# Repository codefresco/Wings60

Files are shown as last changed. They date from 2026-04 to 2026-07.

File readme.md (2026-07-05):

# Wings60

Wings60 is an open source split keyboard designed after trying many existing split layouts.

## Why this layout

This keyboard is different in:

- Improved key access for the thumb cluster, two 1.5u key with good access.
- Uses a natural thumb cluster orientation selected after testing many existing layouts.
- Uses the most popular column stagger.
- Keeps the same PCB usable for wired or wireless builds, including a power slide switch, JST PH2.0 battery plug, and between-halves interconnects on the PCB.
- Uses USB-C for wired interconnect between halves, it can be hot-plugged without damaging microcontrollers.
- Supports pro-micro pinout controllers such as Nice!Nano, Pro Micro ATmega32u4, and Pro Micro RP2040.
- Uses low-power RGB LEDs (SK6803 mini-e), which draw less power than common WS2812B and SK6812 variants.
- Includes a slide switch to cut LED power for zero LED idle current in power-conscious assemblies.
- Stays compact while keeping a top number row.

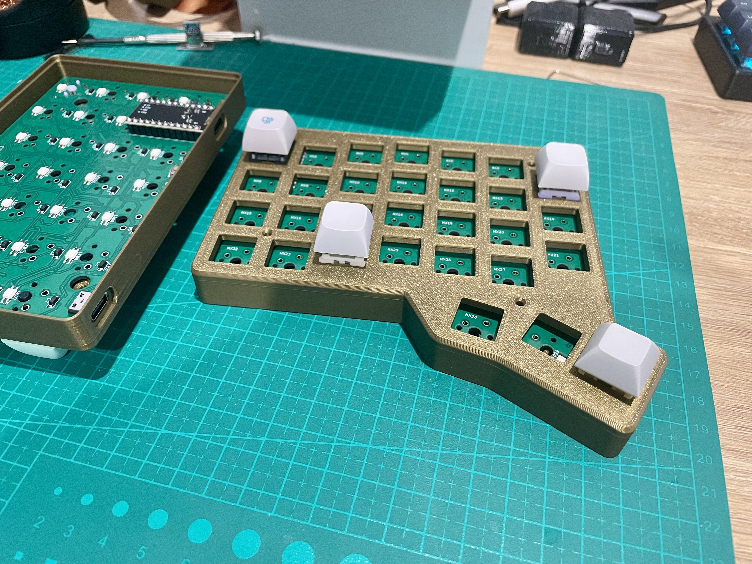
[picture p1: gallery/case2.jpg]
Wings60 case view


## How to assemble

> [!WARNING]
> If you use a 3V microcontroller (for example Nice!Nano or RP2040), do not plug a powered USB cable into the between-halves interconnect USB-C port. With a standard usb c cable and device, this would not be an issue bacause the CC pin on the interconnect is not connected. With a floating CC pin the device would not power the USB-C port. However, some USB-A to USB-C cables or devices do not comply with this standard and present 5v to the USB-C VBUS anyway, and this can damage the microcontroller. To make it mistake proof:
> - For nice! nano compatible and wireless builds print the case with interconect port covered
> - For wired builds with 3V microcontrollers do not connect he VCC pin on microcontroller to the pcb (don't pin if using mill max or similar pins, clip the pin if using ez solder, etc.) and bridge the VCC pin of the PCB to RAW using a short wire on back of the PCB

> [!WARNING]
> Before soldering switches, make sure the microcontroller USB connector is clearly accessible in your chosen case. After switches are soldered, the case top is sandwiched between switches and PCB, and changing the top case becomes difficult. If you want to be able to remove the PCB more easily, check the PCB-mount-switches case variant in [case](./case).

### Bill of materials

- See designs in [case](./case), pick one and print it. You can also design your own case around the [Case design outline](./case/design-outline), both dxf and svg are included.
- Sockets for MCU: one of EZ-Solder Machine Sockets or a 40-pin machined IC breakable female header strip with Mill-Max pins is recommended for a total socket height of 4.5-5mm. This works best with the 3D printable case designs in [case](./case). Check USB connector height after assembly against the case USB opening. If your USB sits higher/lower, use the adjustable USB case variant described in [case/readme.md](./case/readme.md). A good guide to socketing microcontrollers is available here: [Machine pin socket guide](https://github.com/joric/nrfmicro/wiki/Sockets#machine-pin-socket)
- Two pro micros: use any board with firmware already available in [firmware](./firmware), or any pro-micro-pinout compatible board and adjust firmware as needed. For wireless, use Nice!Nano or compatible SuperMini nRF52840.
- Either 4x 9-10mm standoffs with 4x M2x8 and 4x M2x4 screws for each half, or 4x M2x4 heat inserts with the heat-insert-compatible case bottom. See [case/readme.md](./case/readme.md).
- Non-slip rubber feet, 4x per half. 6mm diameter x 2mm height works well.
- [Wired only] A USB-C to USB-C cable for connecting the right and left halves.
- [Wireless only] A JST PH2.0 battery up to 5mm height. Check dimensions against the case if using the designs in [case](./case).
- Switches and keycaps.

### Wired build

1. Flash firmware using instructions here [firmware/readme.md](./firmware/readme.md)
2. Solder and socket the microcontrollers to PCBs, **face down**. USB side must face the PCB. A good socketing guide: [Splitkb microcontroller guide](https://docs.splitkb.com/product-guides/aurora-series/build-guide/microcontrollers)
3. Check USB height to make sure it fits the case designs in [case](./case). If it fits fixed-USB, use that variant; otherwise adjust USB height in the movable/adjustable variant in your slicer.
4. Fit switches to the case, minding pin orientation.

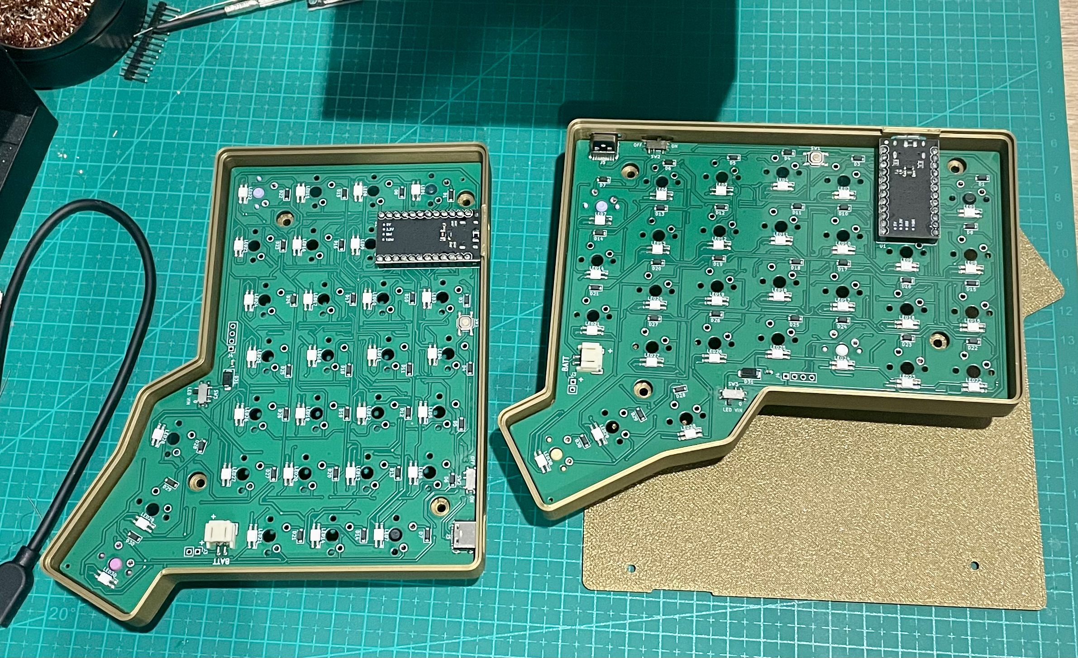
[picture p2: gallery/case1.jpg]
Assembly orientation


5. Fit the PCB to the case with flat side toward switches and components facing away from switches, so switch pins come out through the PCB. PCB should rest on the bottom of the switches. You may need gentle pressure for switch mounting pins to pop in.
6. Check no switch has popped out, and all switches are firmly seated on top of the case top side. Then solder all switch legs to the PCB.
7. If using standoff bottoms, screw each standoff to the case with M2x8 screws. V-shaped heads sit flush in the top-side recesses.
8. Screw case bottoms to standoffs using M2x4 screws, then apply non-slip feet.
9. If using heat-insert bottoms, install heat inserts and fit the bottom to the top using M4x8 screws.

The halves can now be connected using the USB-C cable. Connect one microcontroller to your PC (either half, but not both).

Use [Vial](https://get.vial.today/) to configure the keyboard. Configuration is saved to the half connected to the PC.

### Wireless build

TBD

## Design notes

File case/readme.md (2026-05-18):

## Warning
Before soldering switches, confirm that the case USB opening lines up with your microcontroller's USB port position on the PCB.

| Example 1 | Example 2 |
| --- | --- |
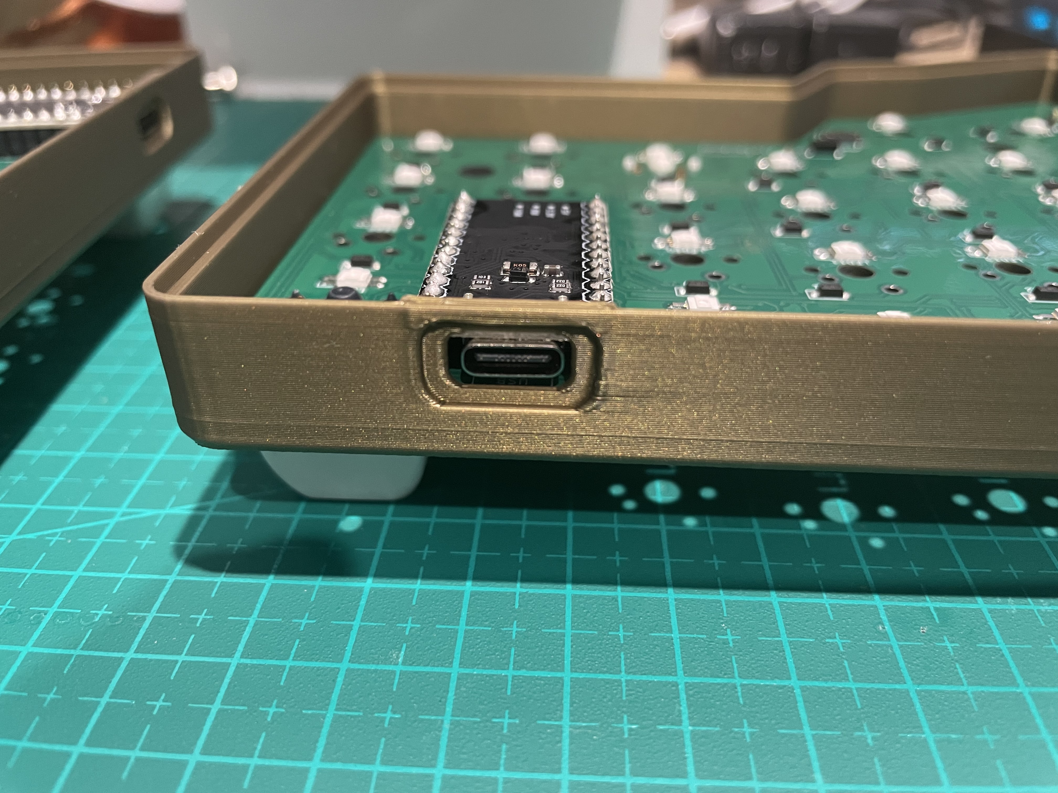
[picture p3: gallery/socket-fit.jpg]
Socket fit
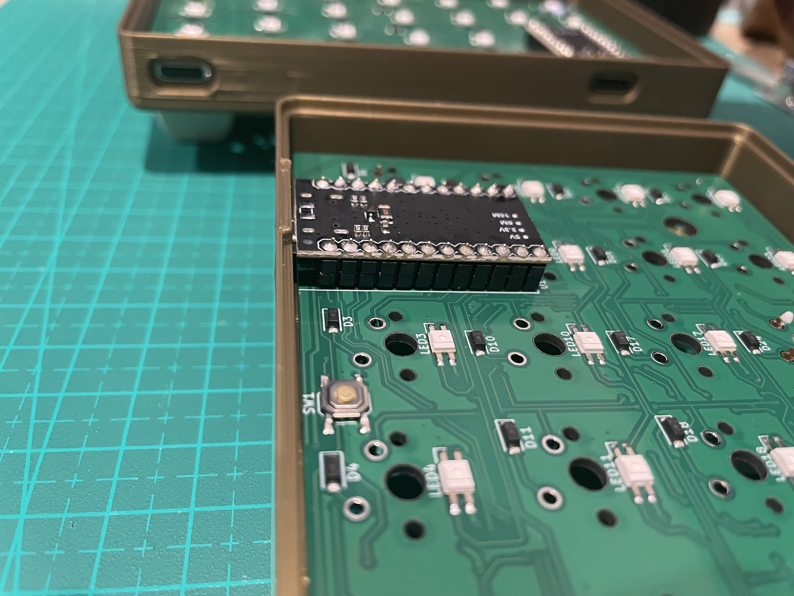
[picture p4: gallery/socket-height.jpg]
Socket height
|  |  |

## Printable Case Types
- **Fixed-height USB opening** (`*-usb-fixed-5mm.3mf`)
	- For total microcontroller socket height of **4.5-5 mm**.
	- Intended for controllers with the USB port mounted on top of the PCB.
- **Movable USB opening** (`*-usb-movable.3mf`)
	- Includes a USB opening as a **negative part** (for Bambu Studio).
	- You can move this part up or down on the **Z axis** to match your board and socket height.

## Which Case Should You Use?
- **`case-wired-usb-fixed-5mm.3mf`**
	- For wired builds with total socket height of **4.5-5 mm**.
	- For MCU boards with the USB connector on top of the PCB.
	- The power-switch opening is covered.

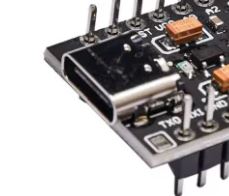
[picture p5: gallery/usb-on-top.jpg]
MCU with USB on top
	
- **`case-nice-nano-and-rp2040-usb-movable.3mf`**
  - For wired or wireless builds with total socket height of **4.5-5 mm**.
  - For boards with a USB connector recessed into the board (for example, nice!nano or Tenstar RP2040 Pro Micro).
  - Includes a power-switch opening by default.
  - You can move the USB negative object in Z and optionally remove the power-switch opening for wired builds.
  - This is the most adjustable 3MF option.

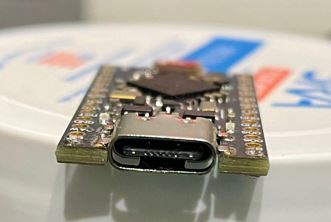
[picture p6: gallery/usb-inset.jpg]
MCU with USB inset
  
- **`case-wired-usb-movable.3mf`**
	- For wired builds.
	- Includes a movable negative object for the USB opening.
	- Adjust USB opening height to fit your specific MCU and mounting height.
- **`case-for-pcb-mount-switches.3mf`**
	- Designed for PCB-mount switches and is less forgiving than other options.
	- The top plate is optional and removable; it does not hold switches permanently.
	- Switches sit directly on the PCB in this build.
	- If you use the top plate, install it before soldering and ensure:
		- switches are fully seated on the PCB,
		- the plate is fully touching the PCB.
	- Due to tight tolerances, soldering switches first may prevent the top case from fitting later.
	- Recommended approach: tape the plate to the PCB, solder switches in the corners first, then solder the rest.

## Bottom, Hardware, and Fasteners
- The bottom included in each 3MF is designed for **9-10 mm standoffs**.
- Use **M2x8 screws (4 pcs)** for the top.
- Use **M2x4 screws (4 pcs)** for the bottom.
- Use **4 standoffs per side**.

## Heat-Insert Bottom Variant
A separate bottom file is available: **`bottom-for-heat-inserts.3mf`**.
- Accepts **M2x4 heat inserts** instead of standoffs.
- Use inserts intended for plastic insertion (not inserts for injection-molded plastic).
- Install inserts accurately for proper fit.
- This variant can provide a better sound profile.

Wings60 Case Bottom

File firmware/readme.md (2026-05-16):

# Wings60 Firmware

This directory contains both source and precompiled firmware for the Wings60 keyboard.

- Source code is in [wings60](wings60) if you want to modify or compile firmware yourself. See [wings60/readme.md](wings60/readme.md) for details.
- Compiled firmware is available in [release](release), ready to flash onto your keyboard.

## Flashing Firmware

| Microcontroller Type | Flashing Guide |
| --- | --- |
| Promicro Atmega32u4 | [Guide](./release/promicro_atmega32u4/readme.md) |
| Nice! Nano (or compatible) | TBD |
| Promicro RP2040 | [Guide](./release/promicro_rp2040/readme.md) |
| STM32 Blackpill | TBD |

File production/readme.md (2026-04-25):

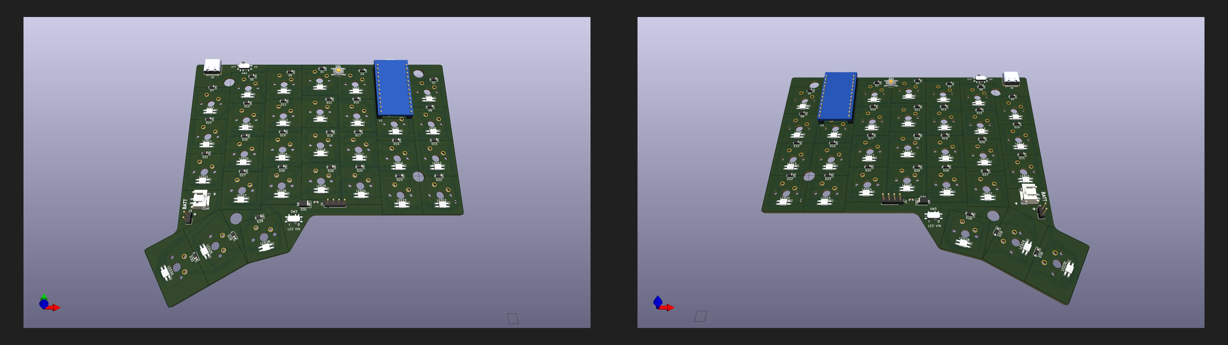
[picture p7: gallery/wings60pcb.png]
Wings60 PCB


## Production Files

You can order this split keyboard from any major PCB manufacturer using the production-ready files in this directory.

- `left/` contains manufacturing files for the left PCB
- `right/` contains manufacturing files for the right PCB

## Example: Ordering from JLCPCB

1. Open JLCPCB and start a new PCB order.
2. Upload the left and right Gerber ZIPs separately (one order per side).
3. Confirm board specs (dimensions, thickness, copper weight, solder mask color, and finish).
4. Keep defaults unless you need specific changes.
5. Add both boards to cart, review, and place the order.

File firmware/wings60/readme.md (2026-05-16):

# Wings60

wings60

* Keyboard Maintainer: [hamid](https://github.com/codefresco)
* Hardware Supported: *Atmega32u4, Weact Blackpill F411, R2040*

See the [build environment setup](https://docs.qmk.fm/#/getting_started_build_tools) and the [make instructions](https://docs.qmk.fm/#/getting_started_make_guide) for more information. Brand new to QMK? Start with our [Complete Newbs Guide](https://docs.qmk.fm/#/newbs).

## Building firmware for Wings60

### Pro micro atmega32u4
Variants with an avr pro micro have less firmware space available, so some vial features are disabled and only the 3 layer keymap fits. Please review in rules.mk.

Compile firmware (or grab from release directory) for left and right sides, for atmega32u4.
```
qmk compile -kb wings60/avr/left -km vial3layer
qmk compile -kb wings60/avr/right -km vial3layer
```

To flash the resulting `wings60_avr_left_vial3layer.hex` and `wings60_avr_right_vial3layer.hex` file use avrdude:

```
avrdude -p atmega32u4 -c avr109 -P [YOUR_COM_PORT] -U flash:w:wings60_avr_left_vial3layer.hex:i
```
replace [YOUR_COM_PORT] with the com port that the pro micro is connected and double tap SW1 on the pcb (reset button) before flashing. Repeat for the right side.

## Pro micro RP2040Based on a raspberry pico rp2040 with pro micro footprint.

Compile and flash firmware (or grab from release directory) for left and right sides, for rp2040.
```
make wings60/rp2040:vial:uf2-split-left
make wings60/rp2040:vial:uf2-split-right
```
Each command also generates a `wings60_rp2040_vial.uf2` in `vial-qmk` root directory. If you want to keep that file, rename after each half and copy it to somewhere else so it does not get overwrittern by the next half.

**Note:** some borads do not go into bootloader by double tapping reset, for first flash you might have to hold the boot switch and connect the usb. Subsequent flashes will work by double tapping the reset key on the PCB.

## Bootloader

Enter the bootloader in 3 ways:

* **Bootmagic reset**: Hold down the key at (0,0) in the matrix (usually the top left key or Escape) and plug in the keyboard
* **Physical reset button**: Double tap the SW1 butoon on the PCB
* **Keycode in layout**: Press the key mapped to `QK_BOOT` if it is available

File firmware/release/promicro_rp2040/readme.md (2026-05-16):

# Flashing Pro Micro (RP2040) Firmware

This directory contains prebuilt firmware for for the **Pro Micro RP2040** version of the Wings60:

- `wings60_rp2040_left_vial.uf2`
- `wings60_rp2040_right_vial.uf2`

Flash the **left** file to the left half, and the **right** file to the right half.

## Before you start

You will need to put your RP2040 board into bootloader mode. This brings up a drive where you can copy the uf2 file there.

If you have brand new boards they should go into bootloader and bring up the drive after connecting them to your PC via USB. However, some boards already have firmware on and depending on what firmware is on the board you should be able to either **double tap reset (or short reset pin to ground twice)** to enter bootloader, **or hold the boot switch and connect USB.** So it would be a good idea to **flash firmware to your boards before socketing them into Wings60 PCB.**

After you flash Wings60 firmware once, subsequent flashing can be done by double tapping the reset switch **SW1** on the Wings60 pcb.

## Important notes

- Flash **one half at a time**
- Unplug the other half while flashing to avoid confusion

## Troubleshooting

### Double tapping reset switch does not put the contrller into bootloader

This is common with some boards, to flash you would have to hold the boot switch on the board if it has one, or short the Boot pin to ground and connect the board to USB.

### Columns on the keyboard are reversed

This happens if you flash the right side firmware to left and vice versa. Flash the correct half to fix.

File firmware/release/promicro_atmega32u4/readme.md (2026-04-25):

# Flashing Pro Micro (ATmega32U4) Firmware

This folder contains prebuilt firmware for the **Pro Micro ATmega32U4** version of Wings60:

- `wings60_avr_left_vial3layer.hex`
- `wings60_avr_right_vial3layer.hex`

Flash the **left** file to the left half, and the **right** file to the right half.

## Before you start

You will need:

- A USB cable that supports data
- `avrdude` installed on your computer
- The correct COM port for the Pro Micro you are flashing
- A way to reset the controller into bootloader mode

If you need to reset the MCU, you can use the **SW1 reset switch on the PCB**.

## Important notes

- Flash **one half at a time**
- Unplug the other half while flashing to avoid confusion
- The keyboard may show up on a different COM port after reset; this is normal on many Pro Micro boards
- The bootloader stays available only for a short time, so have the command ready before resetting

## Install avrdude

If `avrdude` is not already installed, install it first.

Common options on Windows:

- Use QMK MSYS if you already use QMK tools
- Install `avrdude` through a package manager such as Scoop or Chocolatey
- Use an existing AVR toolchain installation if you already have one

After installation, open a terminal and confirm it works:

```powershell
avrdude -?
```

If that prints help text, `avrdude` is available.

## Find the COM port

1. Plug in the half you want to flash.
2. Open **Device Manager**.
3. Expand **Ports (COM & LPT)**.
4. Note the COM port for the Pro Micro, for example `COM7`.

If you do not see it, try another USB cable or USB port.

## Flash the left half

Open a terminal in this folder and run:

```powershell
avrdude -p atmega32u4 -c avr109 -P COM7 -U flash:w:wings60_avr_left_vial3layer.hex:i
```

Replace `COM7` with your actual port.

If `avrdude` cannot connect, reset the MCU and try again:

1. Press the **SW1 reset switch on the PCB**.
2. If needed, press it twice quickly to enter the bootloader.
3. Run the flash command again immediately.

When flashing succeeds, `avrdude` will report that writing and verification completed.

## Flash the right half

Open a terminal in this folder and run:

```powershell
avrdude -p atmega32u4 -c avr109 -P COM7 -U flash:w:wings60_avr_right_vial3layer.hex:i
```

Again, replace `COM7` with the correct port for the right half.

If needed, use the **SW1 reset switch on the PCB** before running the command.

## Recommended flashing order

1. Unplug both halves.
2. Plug in the left half.
3. Flash `wings60_avr_left_vial3layer.hex`.
4. Unplug the left half.
5. Plug in the right half.
6. Flash `wings60_avr_right_vial3layer.hex`.

## Troubleshooting

### `ser_open(): can't open device`

Usually means the COM port is wrong or the board is not in bootloader mode.

Try this:

- Check the COM port again in Device Manager
- Press the **SW1 reset switch on the PCB** and retry quickly
- Unplug and reconnect the board
- Try a different USB cable

### The COM port changes after reset

This is common for Pro Micro boards. Watch Device Manager while pressing **SW1** and use the port that appears in bootloader mode.

### Flash starts but fails part way through

Try this:

- Disconnect the other half
- Plug directly into the PC instead of a hub
- Reset with **SW1** and retry
- Make sure no other program is using the same COM port

## Summary

- Left half: `wings60_avr_left_vial3layer.hex`
- Right half: `wings60_avr_right_vial3layer.hex`
- MCU: `atmega32u4`
- Programmer: `avr109`
- Reset method: **SW1 reset switch on the PCB**

Use the same `avrdude` command for both halves and only change:

- The COM port
- The `.hex` filename

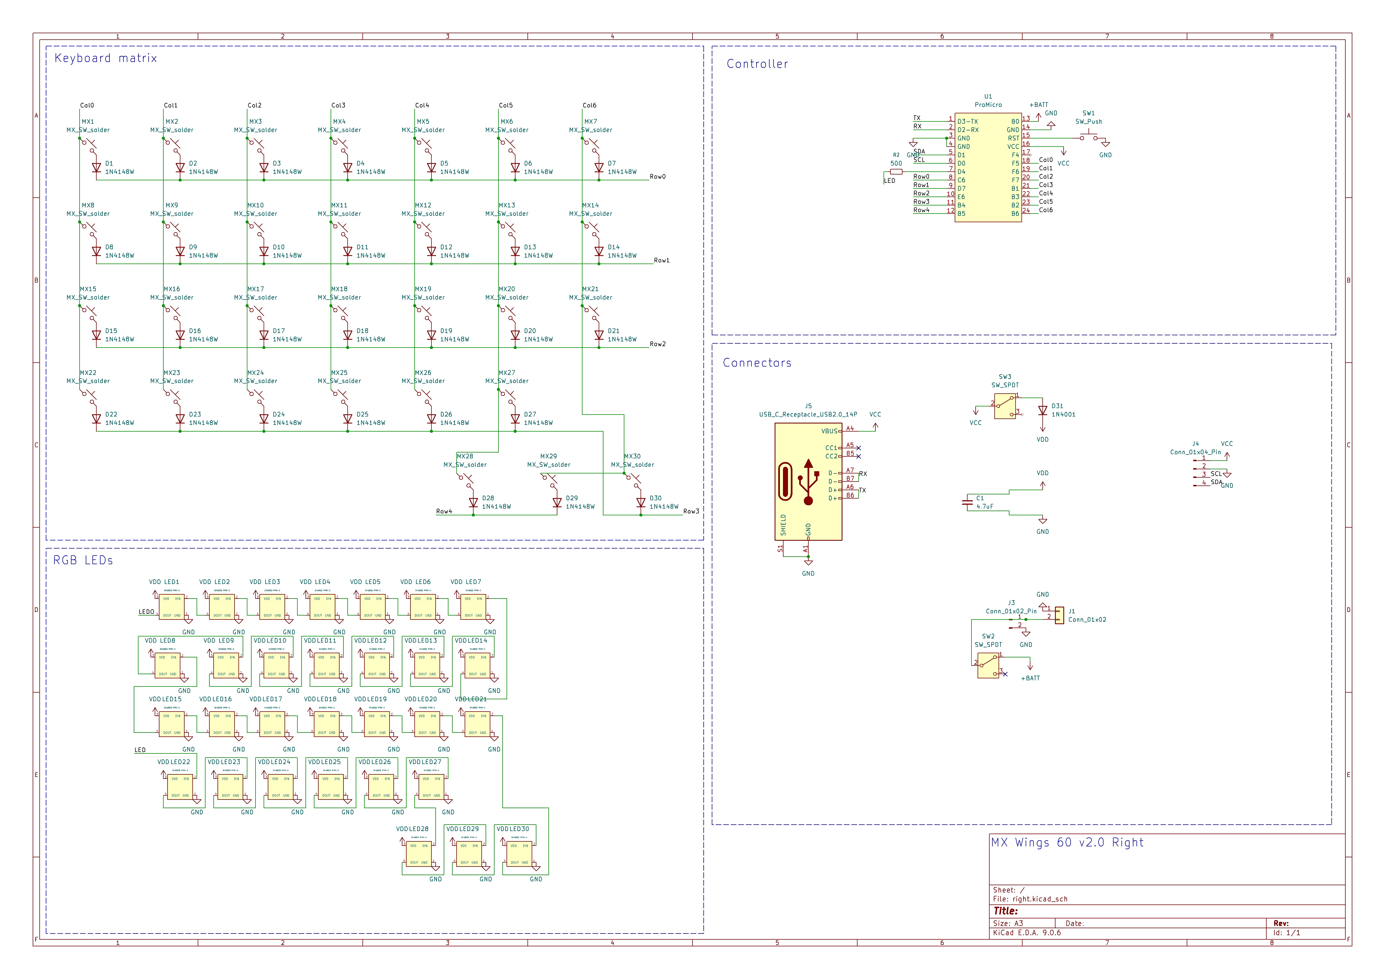
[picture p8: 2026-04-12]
gallery/schematic_right.jpg

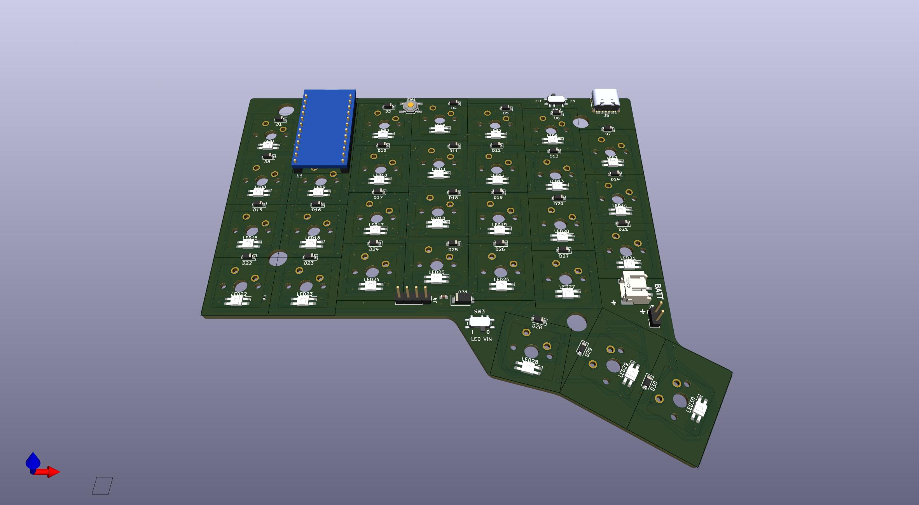
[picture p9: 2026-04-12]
production/kicad/right/right.jpg

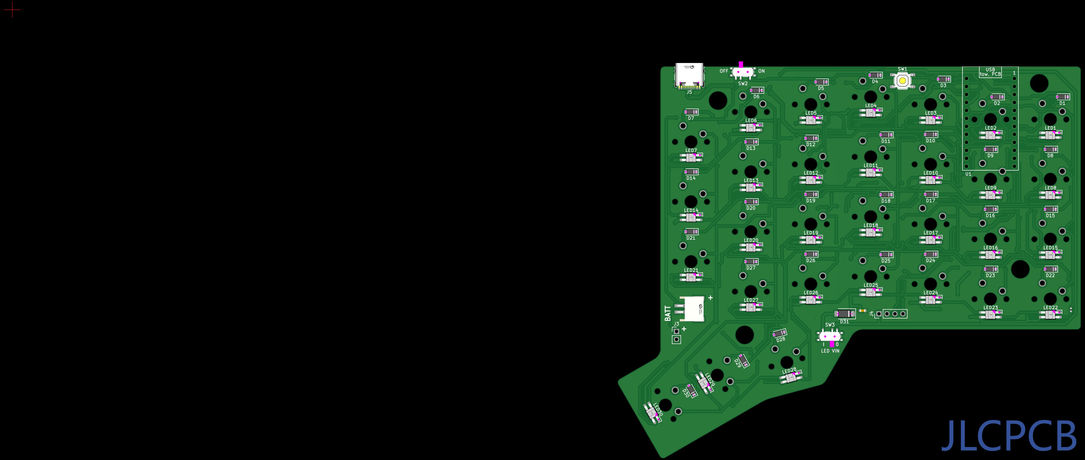
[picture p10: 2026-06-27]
production/kicad/left/left_prod.png

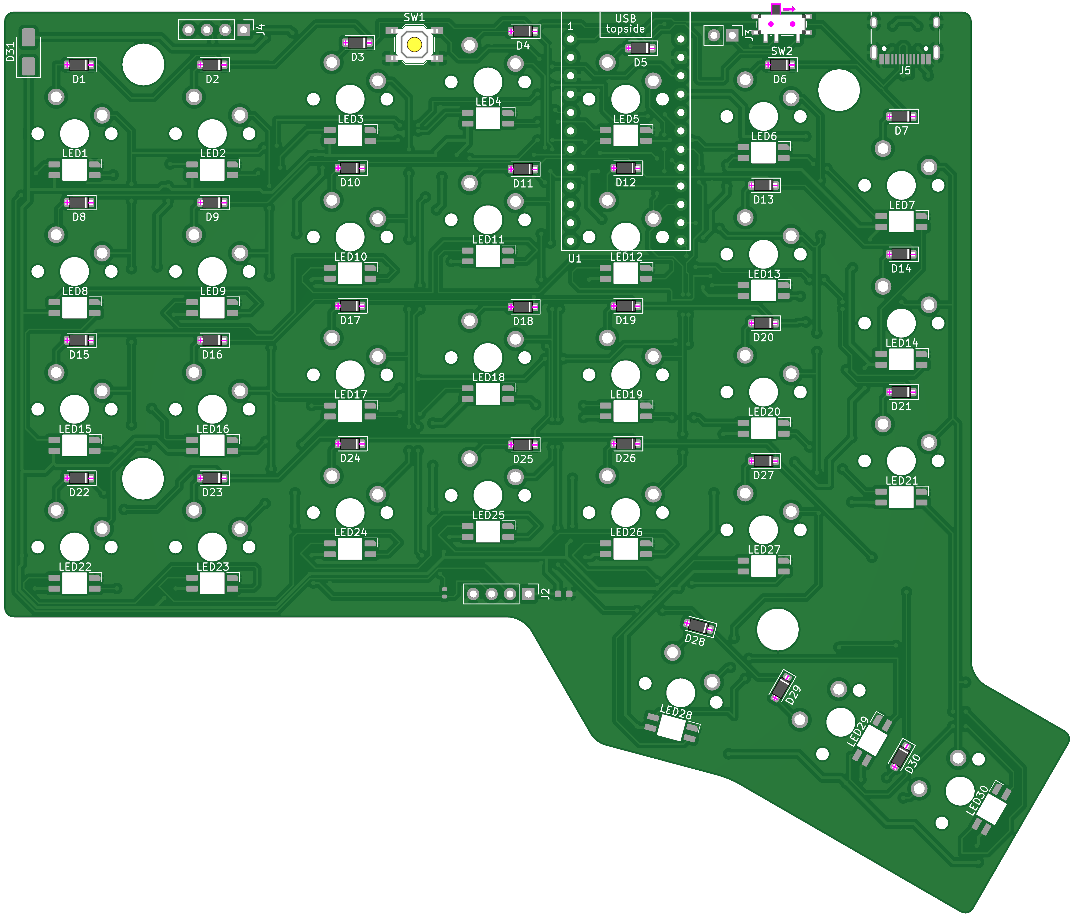
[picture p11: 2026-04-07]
production/kicad/right/right_barebone_prod.png

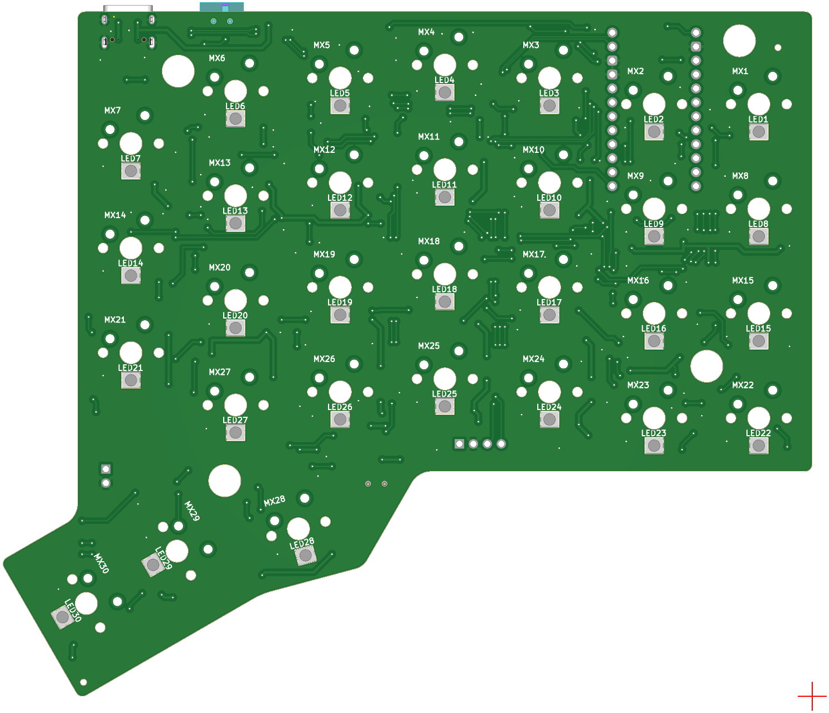
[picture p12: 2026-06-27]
production/kicad/right/Bottom+null+SMT026041160924.png

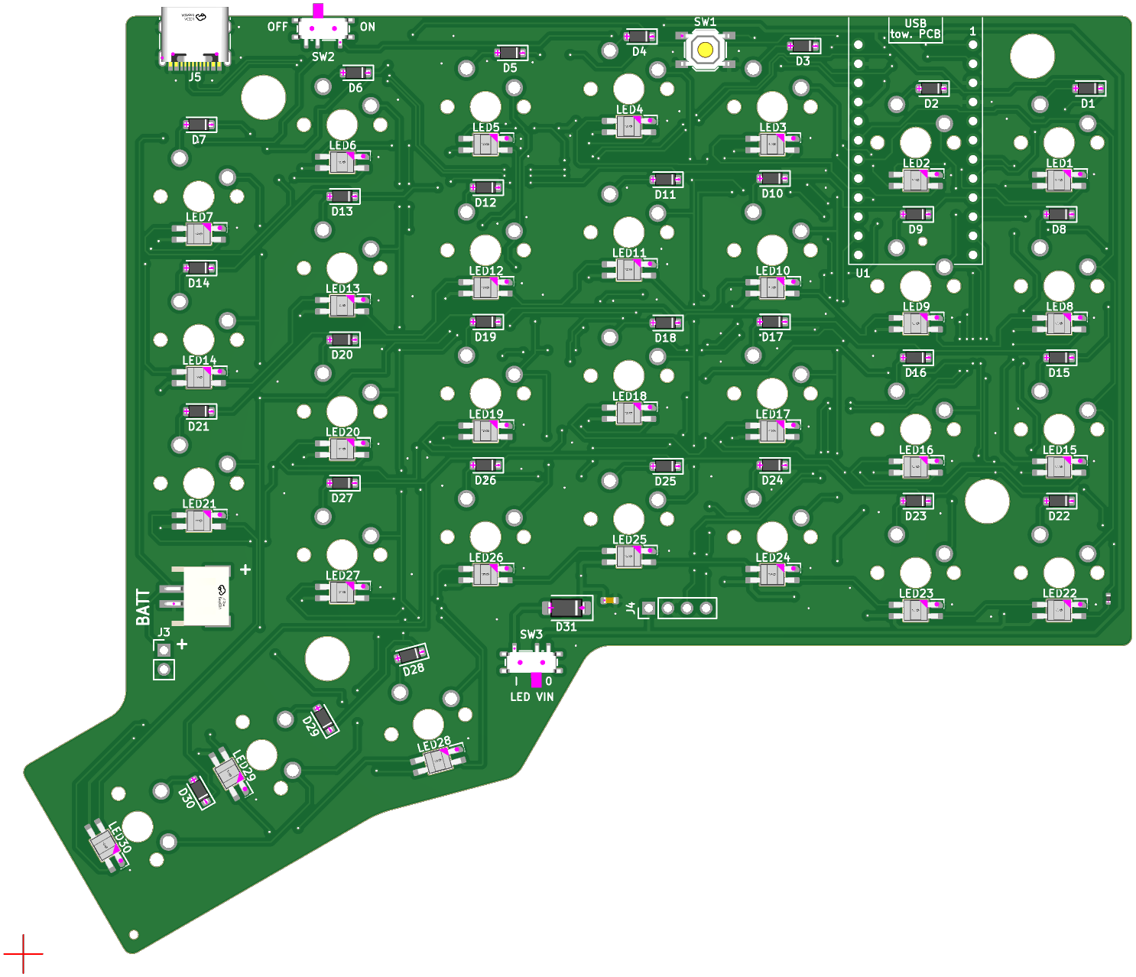
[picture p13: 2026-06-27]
production/kicad/left/Top+null+SMT026041160906.png

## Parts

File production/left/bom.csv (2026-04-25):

Designator | Footprint | Quantity | Value | LCSC Part #
C1 | Capacitor_0603 | 1 | 4.7uF | C19666
D1, D10, D11, D12, D13, D14, D15, D16, D17, D18, D19, D2, D20, D21, D22, D23, D24, D25, D26, D27, D28, D29, D3, D30, D4, D5, D6, D7, D8, D9 | D_SOD-123 | 30 | 1N4148W
D31 | D_SMA | 1 | 1N4001 | C727079
J1 | Connector_1x02_JST-PH | 1 | Conn_01x02 | C295747
J3 | PinHeader_1x02_P2.54mm_Vertical | 1 | Conn_01x02_Pin
J5 | USB_C_Receptacle_HRO_TYPE-C-31-M-12 | 1 | USB_C_Receptacle_USB2.0_14P | C165948
LED1, LED10, LED11, LED12, LED13, LED14, LED15, LED16, LED17, LED18, LED19, LED2, LED20, LED21, LED22, LED23, LED24, LED25, LED26, LED27, LED28, LED29, LED3, LED30, LED4, LED5, LED6, LED7, LED8, LED9 | SK6803_MINI-E_v3.5.5_1 | 30 | SK6803 MINI-E | C5242955
R2 | Resistor_0402 | 1 | 500 | C20607727
SW1 | SW_SPST_TL3342 | 1 | SW_Push | C115351
SW2, SW3 | SW_SPDT_Shouhan_MSK12C02 | 2 | SW_SPDT | C963206

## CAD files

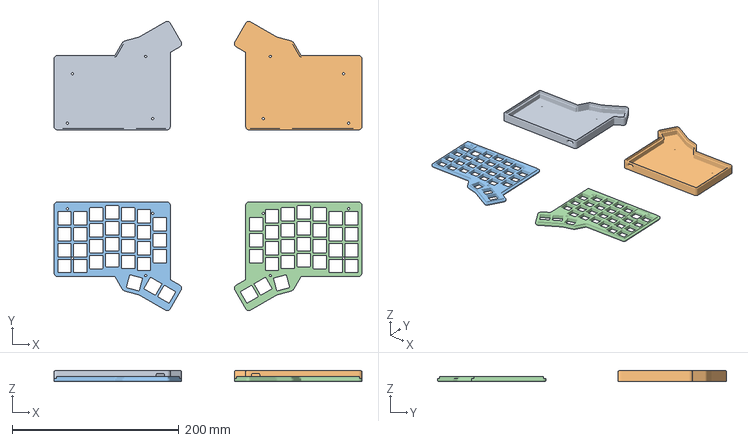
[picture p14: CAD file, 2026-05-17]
case/case-for-pcb-mount-switches.3mf
369.0 x 346.7 x 13.5 mm
modular-v1-wings_60_2_2_right_cuts_edges_shell_with_modifiers_v2_1_botpexp.stl x 2
modular-v1-wings_60_2_2_right_cuts_edges_shell_with_modifiers_v2_1_topcecp.stl x 2

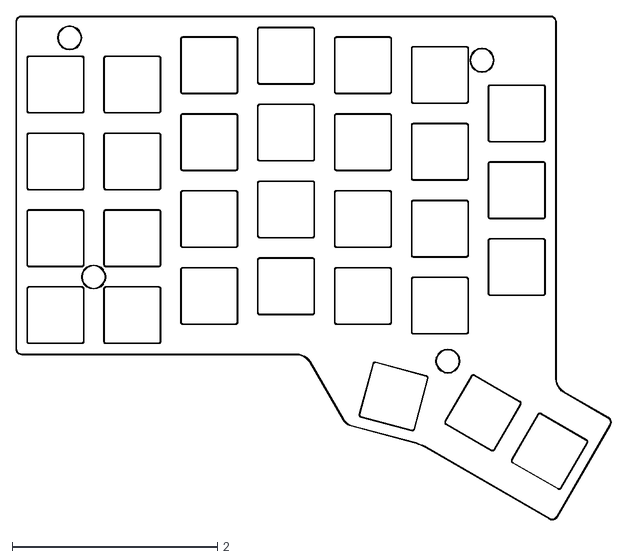
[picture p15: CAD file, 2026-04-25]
case/design-outline/right-User_Eco2.dxf
5.80 x 4.91

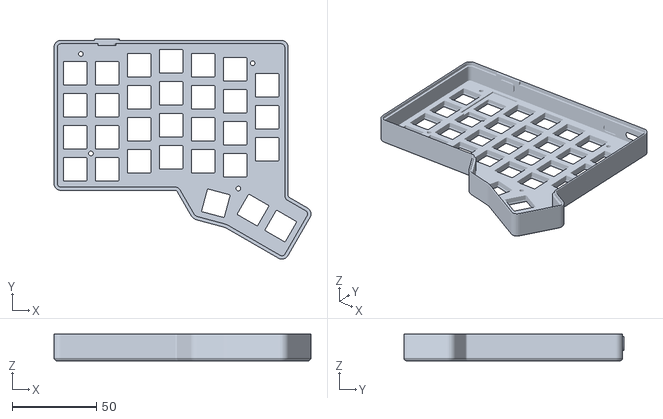
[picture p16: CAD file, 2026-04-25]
case/stl/wired-case-movable-usb.stl
153.0 x 131.2 x 16.0

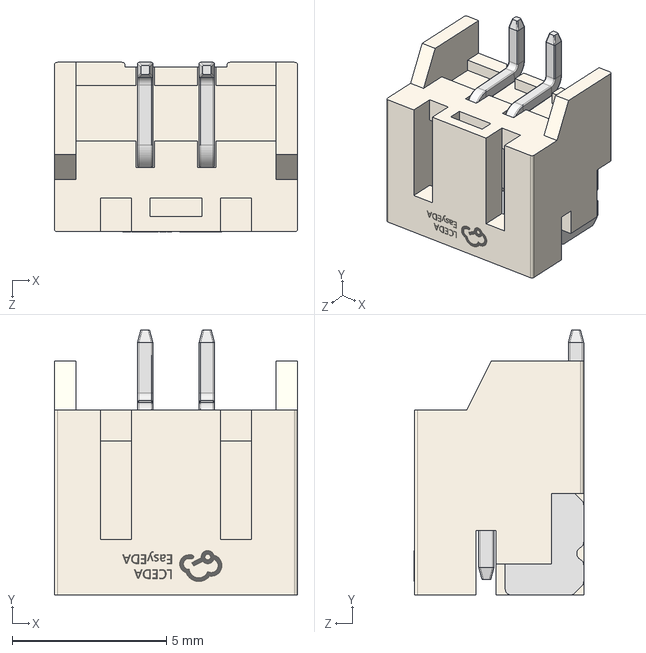
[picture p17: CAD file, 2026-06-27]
production/kicad/3dmodels/JST S2B-PH-SM4-TB(LF)(SN).step
7.90 x 8.60 x 5.50 mm

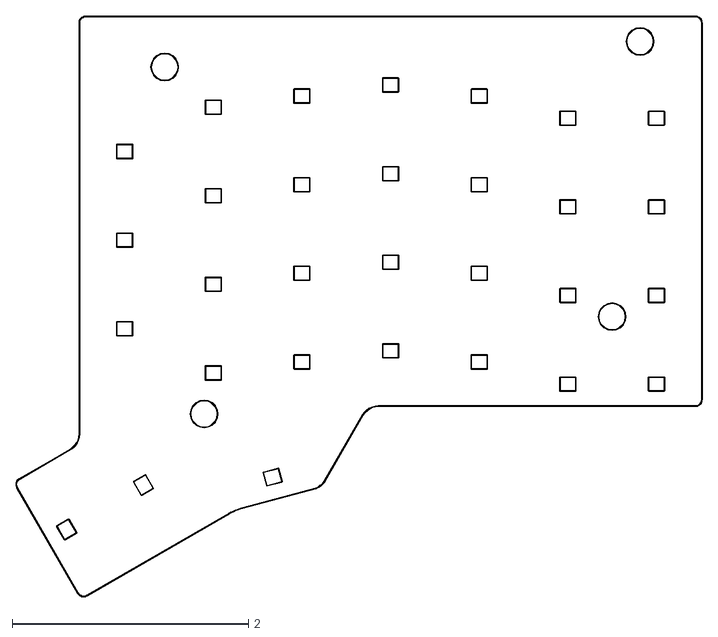
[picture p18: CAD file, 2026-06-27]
production/kicad/left/left-Edge_Cuts.dxf
5.80 x 4.91

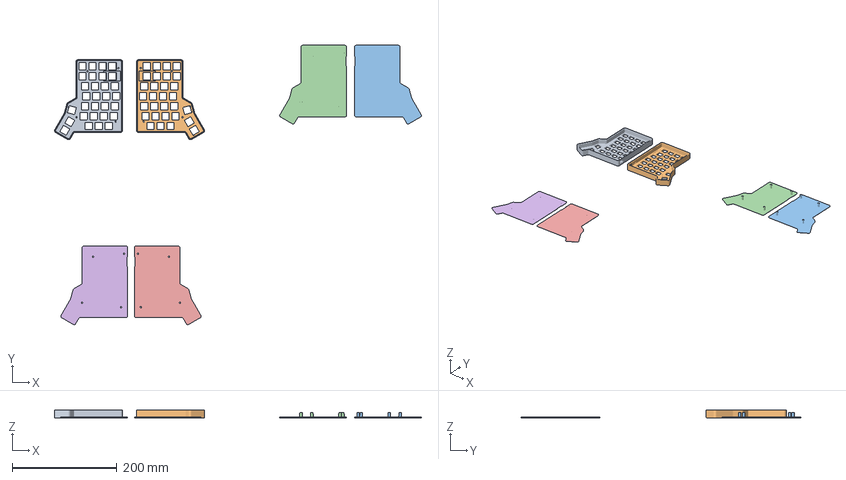
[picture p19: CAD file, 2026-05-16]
case/case-nice-nano-and-rp2040-usb-movable.3mf
701.2 x 534.1 x 16.0 mm
modular-v1-wings_60_2_2_right_cuts_edges_shell_with_modifiers_v2_2_p_exp.stl x 2
modular-v1-wings_60_2_2_right_cuts_edges_shell_bottom_insert_v3_exp.stl x 2
modular-v1-wings_60_2_2_right_cuts_edges_shell_bottom_standoff_v2_exp.stl x 2

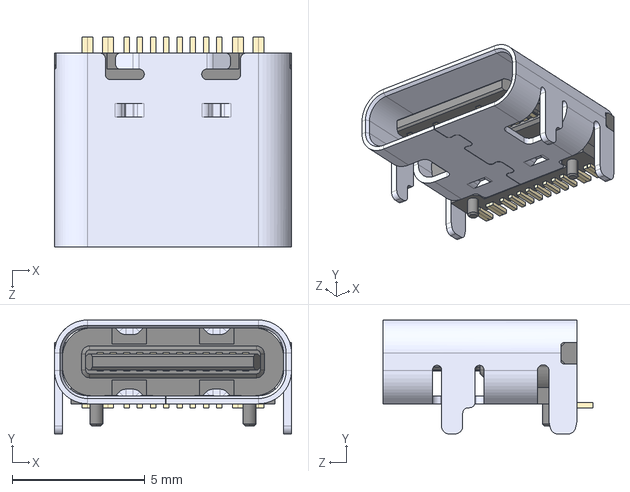
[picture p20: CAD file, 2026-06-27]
production/kicad/3dmodels/USB_C_HRO_TYPE-C-31-M-12.step
8.94 x 4.30 x 7.90 mm

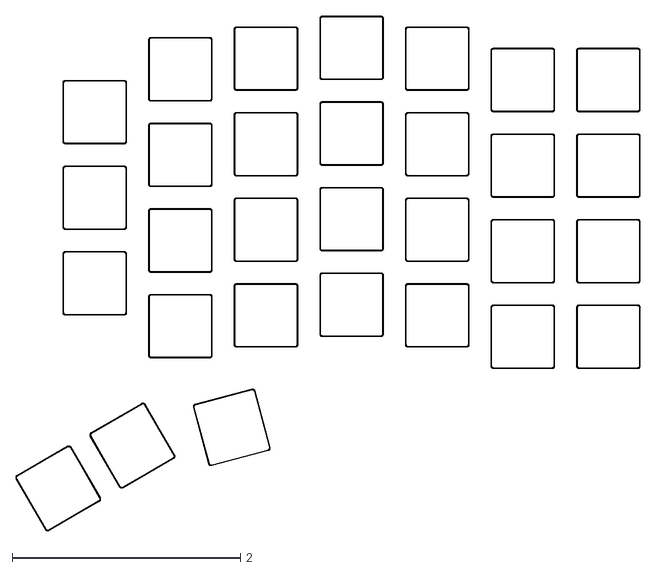
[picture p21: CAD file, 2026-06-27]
production/kicad/left/left-User_Eco2.dxf
5.47 x 4.51

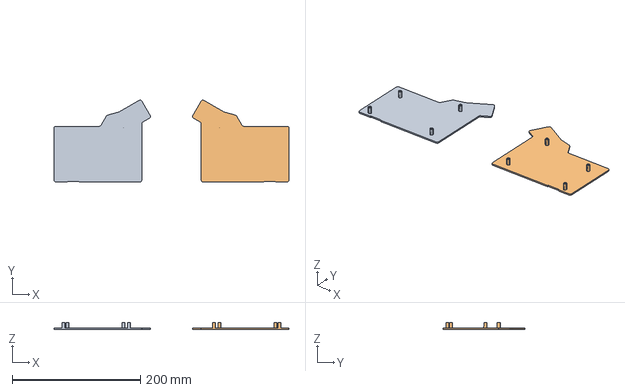
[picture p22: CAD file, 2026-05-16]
case/bottom-for-heat-inserts.3mf
366.6 x 127.8 x 11.0 mm
modular-v1-wings_60_2_2_right_cuts_edges_shell_bottom_insert_v3_exp.stl x 2

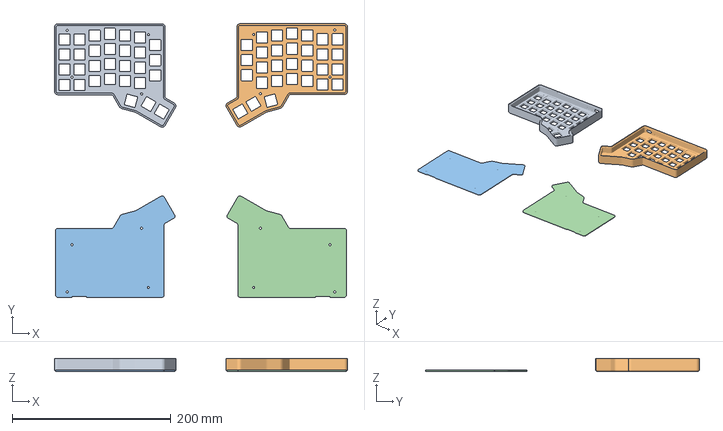
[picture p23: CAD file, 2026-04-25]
case/case-wired-usb-movable.3mf
369.0 x 344.6 x 16.0 mm
case-param.stl x 2
modular-v1-wings_60_2_2_right_cuts_edges_shell_bottom_standoff_v2_exp.stl x 2

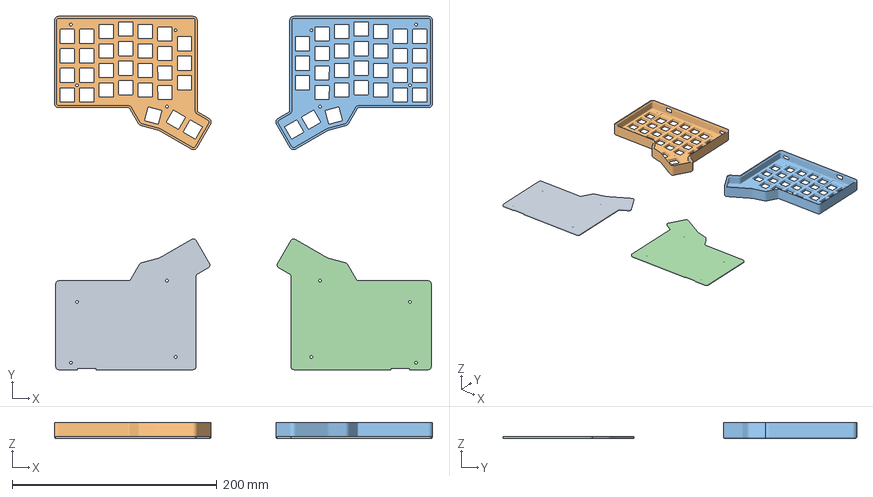
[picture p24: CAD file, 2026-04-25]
case/case-wired-usb-fixed-5mm.3mf
369.0 x 345.1 x 16.0 mm
modular-v1-wings_60_2_2_right_cuts_edges_shell_bottom_standoff_v2_exp.stl x 2
modular-v1-wings_60_2_2_right_cuts_edges_shell_with_modifiers_v2_exp2.stl x 2

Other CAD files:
case/stl/wireless-case-fixed-usb.stl
case/stl/wireless-case-movable-usb.stl
case/stl/wired-case-fixed-usb.stl
case/stl/bottom-for-heat-inserts.stl

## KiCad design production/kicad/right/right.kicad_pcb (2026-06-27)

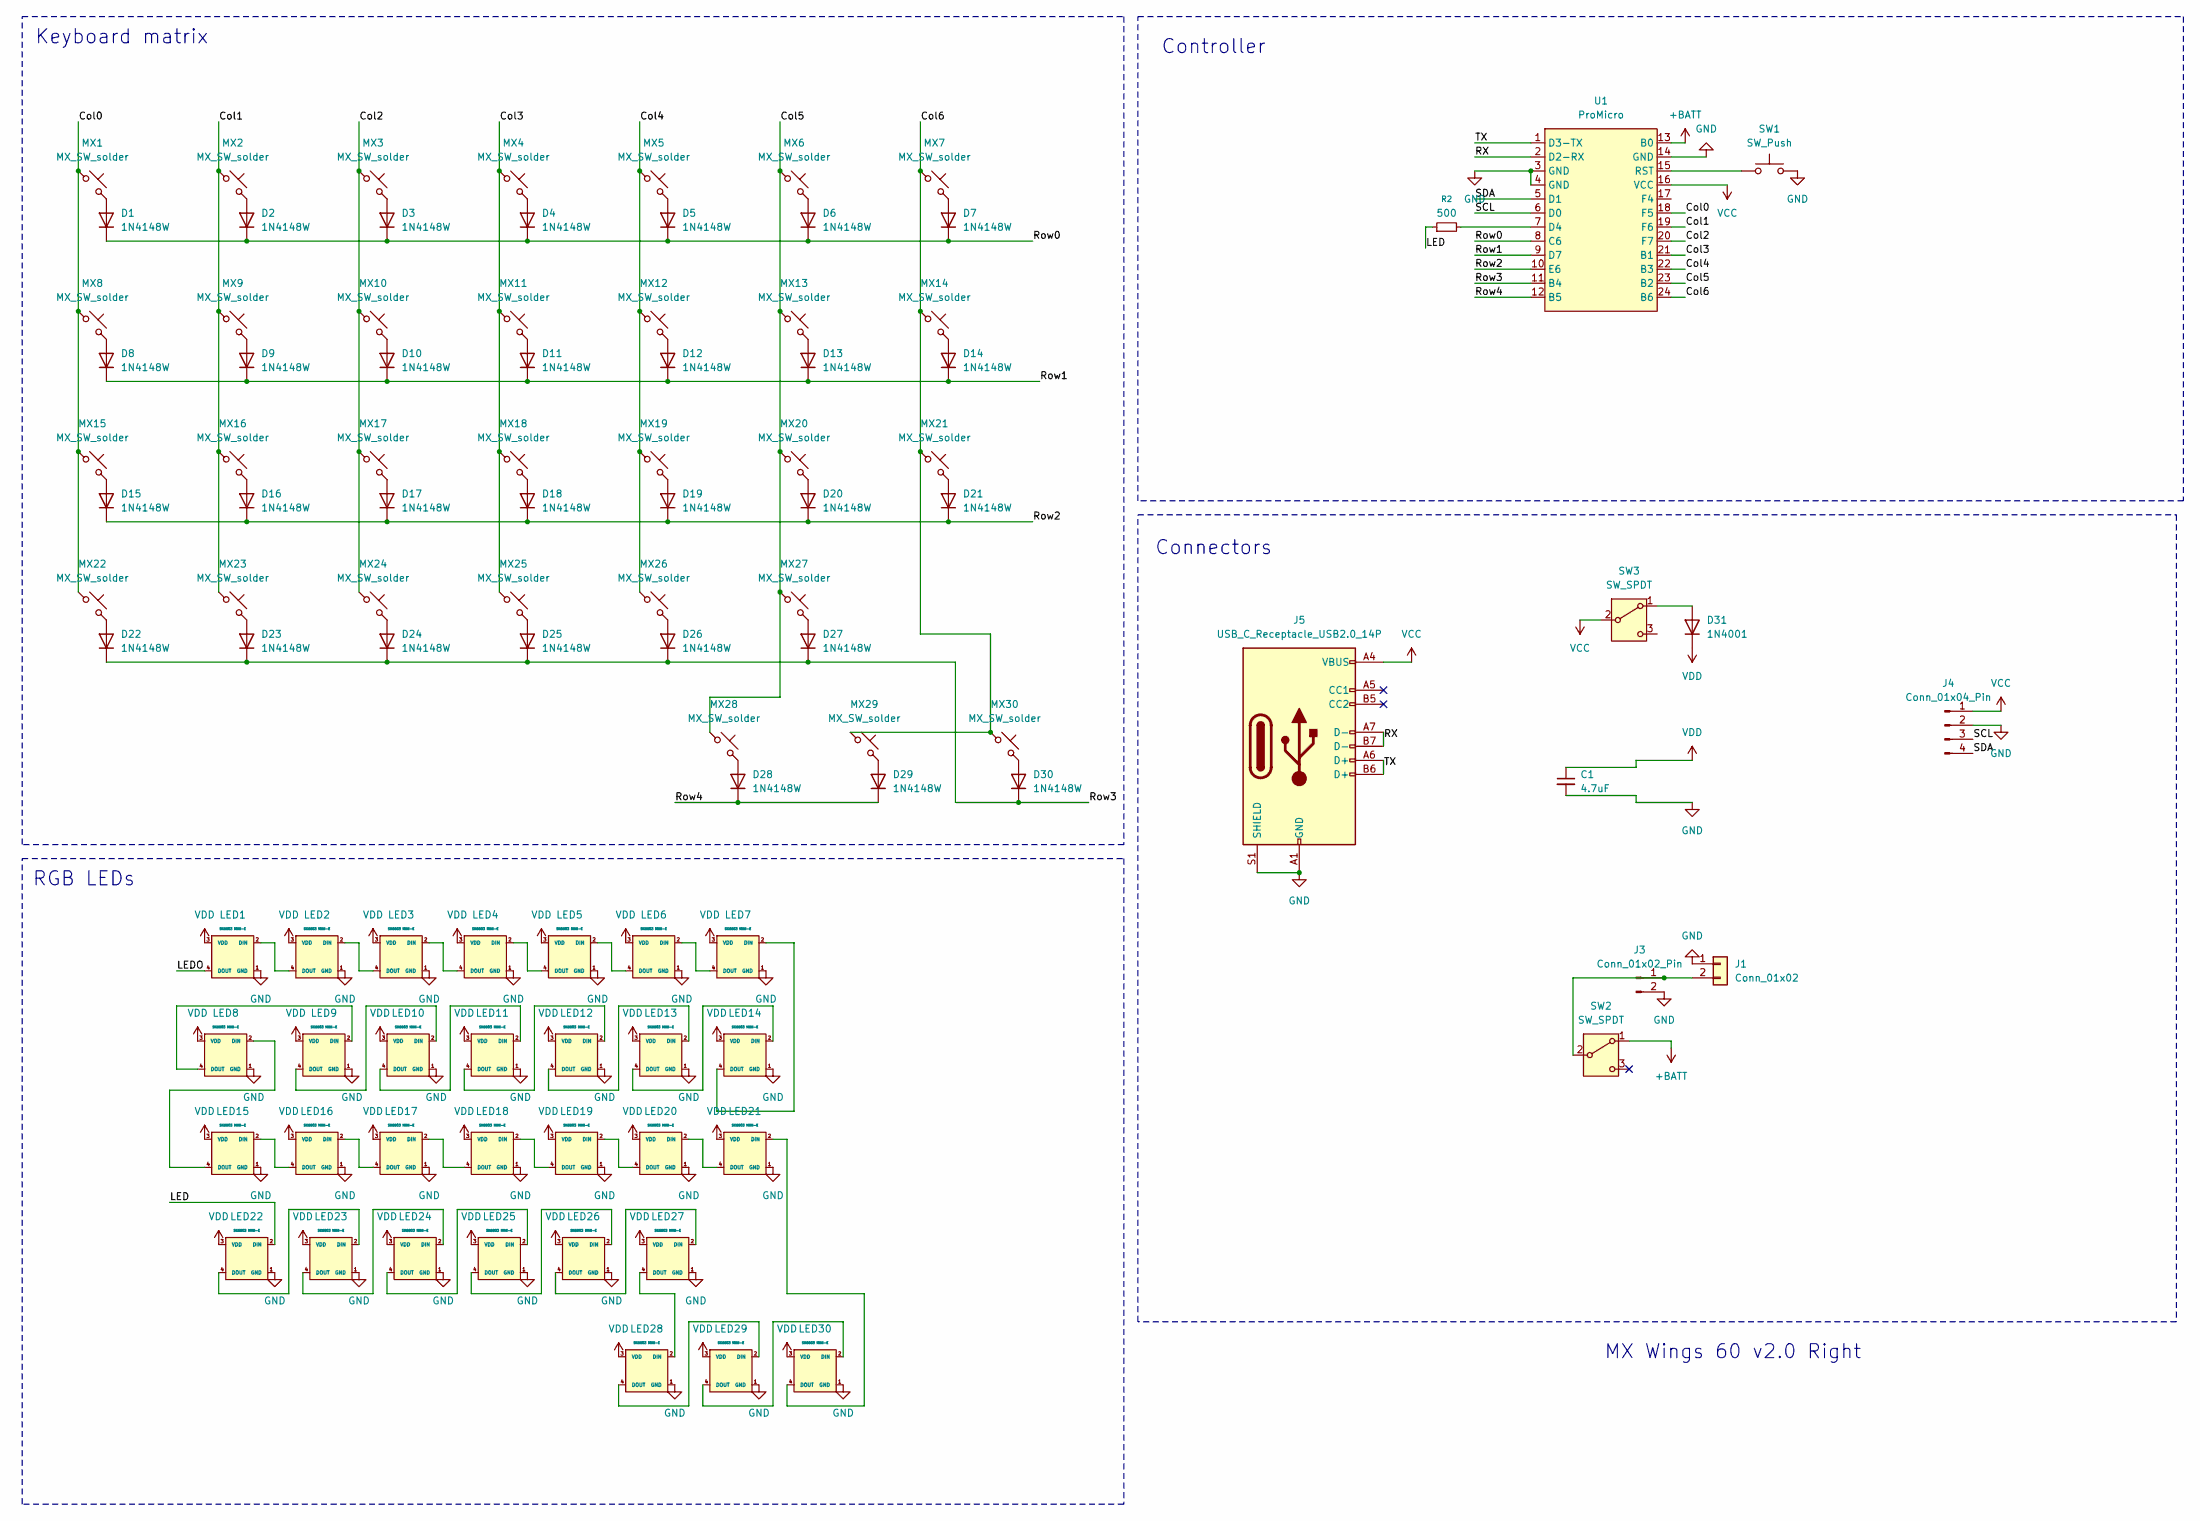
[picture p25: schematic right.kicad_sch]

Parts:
C1: 4.7uF; C_0603_1608Metric; LCSC C19666
D1, D2, D3, D4, D5, D6, D7, D8, D9, D10, D11, D12, D13, D14, D15, D16, D17, D18, D19, D20, D21, D22, D23, D24, D25, D26, D27, D28, D29, D30: 1N4148W; D_SOD-123
D31: 1N4001; D_SMA; LCSC C727079
J1: Conn_01x02; JST S2B-PH-SM4-TB-1x02-JST-PH
J3: Conn_01x02_Pin; PinHeader_1x02_P2.54mm_Vertical
J4: Conn_01x04_Pin; PinHeader_1x04_P2.54mm_Vertical
J5: USB_C_Receptacle_USB2.0_14P; USB_C_Receptacle_HRO_TYPE-C-31-M-12; LCSC C165948
LED1, LED2, LED3, LED4, LED5, LED6, LED7, LED8, LED9, LED10, LED11, LED12, LED13, LED14, LED15, LED16, LED17, LED18, LED19, LED20, LED21, LED22, LED23, LED24, LED25, LED26, LED27, LED28, LED29, LED30: SK6803 MINI-E; SK6803_MINI-E_v3.5.5_1; JLCPCB PN C5242955
MX1, MX2, MX3, MX4, MX5, MX6, MX7, MX8, MX9, MX10, MX11, MX12, MX13, MX14, MX15, MX16, MX17, MX18, MX19, MX20, MX21, MX22, MX23, MX24, MX25, MX26, MX27, MX28: MX_SW_solder; SW_MX_1u
MX29, MX30: MX_SW_solder; SW_MX_1.5u
R2: 500; R_0402_1005Metric; LCSC C20607727
SW1: SW_Push; SW_SPST_TL3342; LCSC C115351
SW2, SW3: SW_SPDT; SW_SPDT_Shouhan_MSK12C02
U1: ProMicro; ProMicro_USBdn

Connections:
+BATT: SW2.1 (A), U1.13 (B0)
/Col0: MX1.1, MX8.1, MX15.1, MX22.1, U1.18 (F5)
/Col1: MX2.1, MX9.1, MX16.1, MX23.1, U1.19 (F6)
/Col2: MX3.1, MX10.1, MX17.1, MX24.1, U1.20 (F7)
/Col3: MX4.1, MX11.1, MX18.1, MX25.1, U1.21 (B1)
/Col4: MX5.1, MX12.1, MX19.1, MX26.1, U1.22 (B3)
/Col5: MX6.1, MX13.1, MX20.1, MX27.1, MX28.1, U1.23 (B2)
/Col6: MX7.1, MX14.1, MX21.1, MX29.1, MX30.1, U1.24 (B6)
/LED: LED22.2 (DIN), R2.1
/LEDO: LED1.4 (DOUT)
/RX: J5.A7 (D-), J5.B7 (D-), U1.2 (D2-RX)
/Row0: D1.1 (K), D2.1 (K), D3.1 (K), D4.1 (K), D5.1 (K), D6.1 (K), D7.1 (K), U1.8 (C6)
/Row1: D8.1 (K), D9.1 (K), D10.1 (K), D11.1 (K), D12.1 (K), D13.1 (K), D14.1 (K), U1.9 (D7)
/Row2: D15.1 (K), D16.1 (K), D17.1 (K), D18.1 (K), D19.1 (K), D20.1 (K), D21.1 (K), U1.10 (E6)
/Row3: D22.1 (K), D23.1 (K), D24.1 (K), D25.1 (K), D26.1 (K), D27.1 (K), D30.1 (K), U1.11 (B4)
/Row4: D28.1 (K), D29.1 (K), U1.12 (B5)
/SCL: J4.3, U1.6 (D0)
/SDA: J4.4, U1.5 (D1)
/TX: J5.A6 (D+), J5.B6 (D+), U1.1 (D3-TX)
GND: C1.2, J1.1, J3.2, J4.2, J5.A1 (GND), J5.A12 (GND), J5.B1 (GND), J5.B12 (GND), J5.S1 (SHIELD), LED1.1 (GND), LED2.1 (GND), LED3.1 (GND), LED4.1 (GND), LED5.1 (GND), LED6.1 (GND), LED7.1 (GND), LED8.1 (GND), LED9.1 (GND), LED10.1 (GND), LED11.1 (GND), LED12.1 (GND), LED13.1 (GND), LED14.1 (GND), LED15.1 (GND), LED16.1 (GND), LED17.1 (GND), LED18.1 (GND), LED19.1 (GND), LED20.1 (GND), LED21.1 (GND), LED22.1 (GND), LED23.1 (GND), LED24.1 (GND), LED25.1 (GND), LED26.1 (GND), LED27.1 (GND), LED28.1 (GND), LED29.1 (GND), LED30.1 (GND), SW1.2, U1.3 (GND), U1.4 (GND), U1.14 (GND)
unnamed: D1.2 (A), MX1.2
unnamed: D2.2 (A), MX2.2
unnamed: D3.2 (A), MX3.2
unnamed: D4.2 (A), MX4.2
unnamed: D5.2 (A), MX5.2
unnamed: D6.2 (A), MX6.2
unnamed: D7.2 (A), MX7.2
unnamed: D8.2 (A), MX8.2
unnamed: D9.2 (A), MX9.2
unnamed: D10.2 (A), MX10.2
unnamed: D11.2 (A), MX11.2
unnamed: D12.2 (A), MX12.2
unnamed: D13.2 (A), MX13.2
unnamed: D14.2 (A), MX14.2
unnamed: D15.2 (A), MX15.2
unnamed: D16.2 (A), MX16.2
unnamed: D17.2 (A), MX17.2
unnamed: D18.2 (A), MX18.2
unnamed: D19.2 (A), MX19.2
unnamed: D20.2 (A), MX20.2
unnamed: D21.2 (A), MX21.2
unnamed: D22.2 (A), MX22.2
unnamed: D23.2 (A), MX23.2
unnamed: D24.2 (A), MX24.2
unnamed: D25.2 (A), MX25.2
unnamed: D26.2 (A), MX26.2
unnamed: D27.2 (A), MX27.2
unnamed: D28.2 (A), MX28.2
unnamed: D29.2 (A), MX29.2
unnamed: D30.2 (A), MX30.2
unnamed: D31.2 (A), SW3.1 (A)
unnamed: J1.2, J3.1, SW2.2 (B)
unnamed: LED1.2 (DIN), LED2.4 (DOUT)
unnamed: LED2.2 (DIN), LED3.4 (DOUT)
unnamed: LED3.2 (DIN), LED4.4 (DOUT)
unnamed: LED4.2 (DIN), LED5.4 (DOUT)
unnamed: LED5.2 (DIN), LED6.4 (DOUT)
unnamed: LED6.2 (DIN), LED7.4 (DOUT)
unnamed: LED8.4 (DOUT), LED9.2 (DIN)
unnamed: LED9.4 (DOUT), LED10.2 (DIN)
unnamed: LED10.4 (DOUT), LED11.2 (DIN)
unnamed: LED11.4 (DOUT), LED12.2 (DIN)
unnamed: LED12.4 (DOUT), LED13.2 (DIN)
unnamed: LED13.4 (DOUT), LED14.2 (DIN)
unnamed: LED7.2 (DIN), LED14.4 (DOUT)
unnamed: LED15.2 (DIN), LED16.4 (DOUT)
unnamed: LED8.2 (DIN), LED15.4 (DOUT)
unnamed: LED16.2 (DIN), LED17.4 (DOUT)
unnamed: LED17.2 (DIN), LED18.4 (DOUT)
unnamed: LED18.2 (DIN), LED19.4 (DOUT)
unnamed: LED19.2 (DIN), LED20.4 (DOUT)
unnamed: LED20.2 (DIN), LED21.4 (DOUT)
unnamed: LED21.2 (DIN), LED30.4 (DOUT)
unnamed: LED22.4 (DOUT), LED23.2 (DIN)
unnamed: LED23.4 (DOUT), LED24.2 (DIN)
unnamed: LED24.4 (DOUT), LED25.2 (DIN)
unnamed: LED25.4 (DOUT), LED26.2 (DIN)
unnamed: LED26.4 (DOUT), LED27.2 (DIN)
unnamed: LED27.4 (DOUT), LED28.2 (DIN)
unnamed: LED28.4 (DOUT), LED29.2 (DIN)
unnamed: LED29.4 (DOUT), LED30.2 (DIN)
unnamed: R2.2, U1.7 (D4)
unnamed: SW1.1, U1.15 (RST)
VCC: J4.1, J5.A4 (VBUS), J5.A9 (VBUS), J5.B4 (VBUS), J5.B9 (VBUS), SW3.2 (B), U1.16 (VCC)
VDD: C1.1, D31.1 (K), LED1.3 (VDD), LED2.3 (VDD), LED3.3 (VDD), LED4.3 (VDD), LED5.3 (VDD), LED6.3 (VDD), LED7.3 (VDD), LED8.3 (VDD), LED9.3 (VDD), LED10.3 (VDD), LED11.3 (VDD), LED12.3 (VDD), LED13.3 (VDD), LED14.3 (VDD), LED15.3 (VDD), LED16.3 (VDD), LED17.3 (VDD), LED18.3 (VDD), LED19.3 (VDD), LED20.3 (VDD), LED21.3 (VDD), LED22.3 (VDD), LED23.3 (VDD), LED24.3 (VDD), LED25.3 (VDD), LED26.3 (VDD), LED27.3 (VDD), LED28.3 (VDD), LED29.3 (VDD), LED30.3 (VDD)

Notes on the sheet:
Connectors
MX Wings 60 v2.0 Right
Controller
RGB LEDs
Keyboard matrix

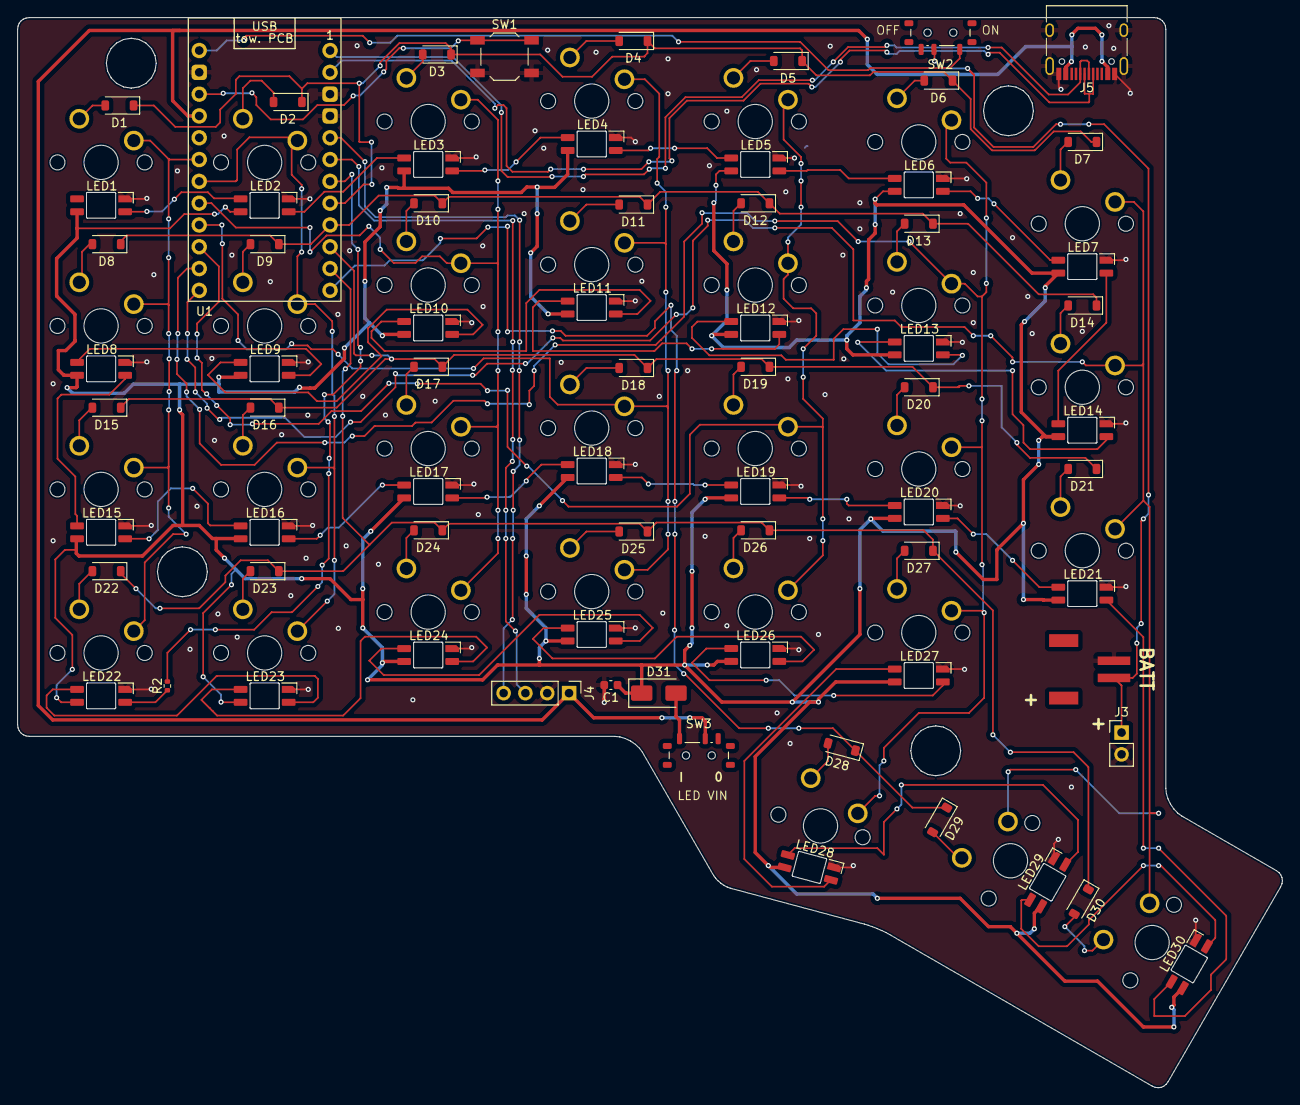
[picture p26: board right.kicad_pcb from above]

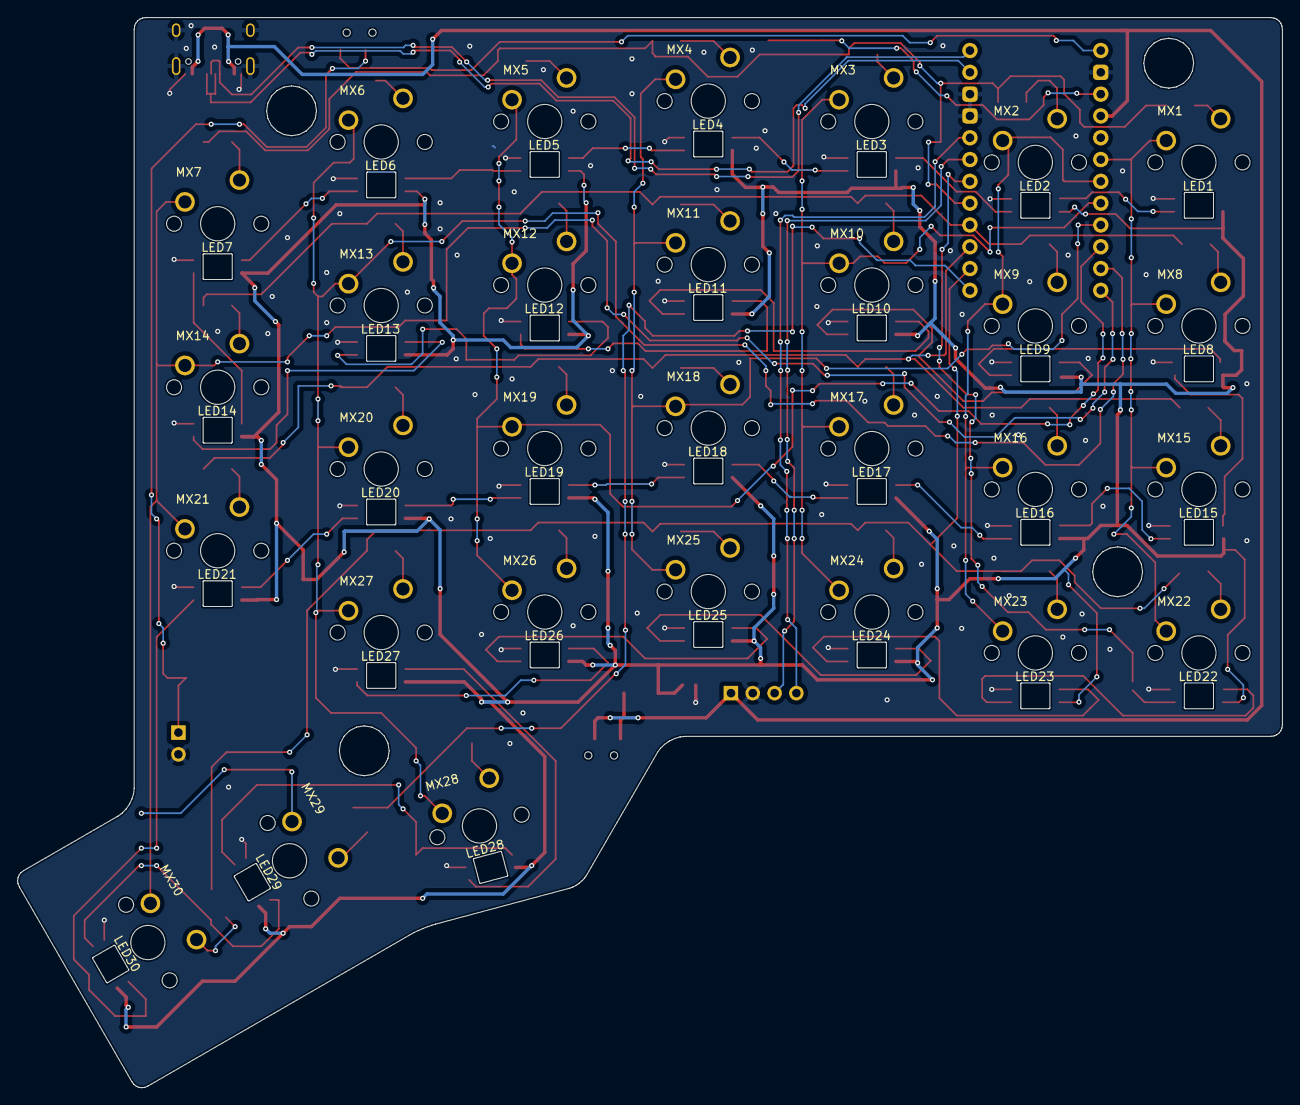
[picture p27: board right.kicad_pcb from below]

Board: 2 copper layers, 147.3 x 124.7 mm, 101 parts (30 on the bottom side), 84 nets.

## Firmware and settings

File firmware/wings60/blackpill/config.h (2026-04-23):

#pragma once

#define SERIAL_USART_FULL_DUPLEX // Enable full duplex operation mode.
#define SERIAL_USART_TX_PIN B6   // USART TX pin
#define SERIAL_USART_RX_PIN B7   // USART RX pin

#define WS2812_PWM_DRIVER PWMD5
#define WS2812_PWM_CHANNEL 2
#define WS2812_PWM_PAL_MODE 2
#define WS2812_DMA_STREAM STM32_DMA1_STREAM6
#define WS2812_DMA_CHANNEL 6

#define EE_HANDS

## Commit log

2026-04-12 Updated MCU position for full compatibility, added switch for led power line
2026-04-23 Wings60 v2 firmware
2026-04-23 Rename Wings60V2 to Wings60 in readme
2026-04-25 Added case
    [bottom-for-heat-inserts.3mf, bottom-for-heat-inserts.stl, case-wired-usb-fixed-5mm.3mf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]
2026-04-25 Added production files and readme
    [bom.csv, positions.csv]
2026-04-25 Added design outline svg and dxf
    [right-User_Eco2.dxf]
2026-04-26 Added case for pcb mounting switches
    [case-for-pcb-mount-switches.3mf]
2026-05-12 Update readme with refined keyboard layout description
    Refined the description of the Wings60 keyboard layout, emphasizing its unique features and improvements over common layouts.
2026-05-16 Added firmware for RP2040
    [bottom-for-heat-inserts.3mf]
2026-05-16 Added case type for mcus with inset usb port
    [case-nice-nano-and-rp2040-usb-movable.3mf, case-wireless-usb-fixed-5mm.3mf, case-wireless-usb-movable.3mf]
2026-05-16 Updated case readme
2026-05-17 Improved case design for pcb mount switches
    [case-for-pcb-mount-switches.3mf]
2026-05-17 Improved pcb mount case top and updated case readme
    [case-for-pcb-mount-switches.3mf]
2026-05-17 Updated main and case readme
2026-05-18 Fixed sample images in case readme, linked to design outline in main readme
2026-05-20 Enhance assembly instructions with safety warnings
    Added additional warnings for 3V microcontroller usage to prevent damage and improve assembly instructions.
2026-06-03 Through hole 4 row choc prototype
2026-06-08 Wing46 prototype
2026-06-25 Wireless dongle pcb
2026-06-27 Added kicad files
    [JST S2B-PH-SM4-TB(LF)(SN).step, USB_C_HRO_TYPE-C-31-M-12.step, left-Edge_Cuts.dxf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]
2026-07-05 Update warning for 3V microcontroller USB connection
    Clarify warning about using powered USB cables with 3V microcontrollers and provide additional precautions.
2026-07-05 Update warning for USB cable usage with 3V microcontrollers
    Clarified warning about using USB cables with 3V microcontrollers in the assembly instructions.
